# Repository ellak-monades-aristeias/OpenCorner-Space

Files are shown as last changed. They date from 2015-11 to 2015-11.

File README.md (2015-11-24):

# OpenCorner-Space
Σκοπός του έργου είναι η δημιουργία ενός ευέλικτου και εύκολου στο στήσιμο συστήματος πατώματος που μπορεί να εφαρμοστεί σε χώρους χωρίς παρέμβαση στο υφιαστάμενο δάπεδο και να φιλοξενήσει pop-up γραφειακούς χώρους, εκδηλώσεις, συνέδρεια, σεμινάρια κ.α. 
Το σύστημα αποτελείται από μονάδες πλαστικών βιομηχανικών παλετών που καλύπτονται από επιφάνειες ξύλου και παραλαβάνουν τις ηλεκτρικές και καλωδιακές εγκαταστάσεις του χώρου (ρεύμα-LAN-τηλέφωνο), αφενός κρύβοντάς τες και αφετέρου διοχετεύοντάς τις στα σημεία όπου είναι απαραίτητες χωρίς αναγκαιότητα μηχανολογικής μελέτης. Έτσι σε ορισμένες παλέτες εμφανίζονται με κατάλληλη σήμανση φωλιές που ο χρήστης μπορεί να ανασηκώσει και να συνδεθεί με τις παροχές. 
Οι ίδιες παλέτες μπορούν να δημιουργήσουν διάφορα μικροεπίπεδα στο χώρο, είτε διαχωρίζοντας έτσι λειτουργίες (κίνηση-στάση, εργασία-ανάπαυση), είτε ακόμα δημιουργώντας καθιστικούς χώρους ανάπαυλας σε επίπεδα, αμφιθεατρικές διαρρυθμίσεις για παρουσιάσεις κ.α  
Τα υλικά της πρότασης είναι απλά και σχετικά χαμηλού κόστους (χρησιμοποιούνται μεταχειρισμένες παλέτες), μεταφέρονται και τοποθετούνται εξαιρετικά απλά, προσαρμόζονται στο μέγεθος και τα χαρακτηριστικά του εκάστοτε χώρου χωρίς να απαιτούν καμία μόνιμη επέμβαση και φυσικά επαναχρησιμοποιούνται. 

## Σε ποίους απευθύνεται - Κοινότητες Χρηστών - Προγραμματιστών(Developers) ##
Χρήστες μπορεί να είναι οργανισμοί, ιδρύματα, δήμοι, ιδιωτικές πρωτοβουλίες για start-ups, εκπαιδευτικά ιδρύματα, φοιτητές κ.α

## Κόστος ##
 ... το επιπλέον κόστος για την χρήση του έργου σας, εάν απαιτείται επιπλέον εξοπλισμός η/και κατασκευή το κόστος ανα μονάδα για 1, 10 ή 100. ...

# Παραδοτέα:  
Κατασκευή δαπέδου επιφανείας 3,60 χ 4,00μ ή μεγαλυτέρου αν είναι δυνατόν από χρωματιστές πλαστικές παλέτες με τελείωμα ξύλου (σανίδες ή επιφάνεια) και λεπτομέρεια ανοίγματος μερους του δαπέδου για να περαστούν καλώδια, πρίζες κλπ.

Τεύχος κατασκευαστικών σχεδίων και οδηγιών κατασκευής

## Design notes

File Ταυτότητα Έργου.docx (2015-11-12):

Ταυτότητα Έργου
OpenCorner: Space
- opendesign -

Σκοπός του OpenCorner: Space είναι η δημιουργία ενός ευέλικτου και εύκολου στο στήσιμο συστήματος πατώματος και πανέλων απομόνωσης χώρου, που μπορεί να εφαρμοστεί σε χώρους χωρίς παρέμβαση στο υφιαστάμενο δάπεδο και να φιλοξενήσει pop-up γραφειακούς χώρους, εκδηλώσεις, συνέδρεια, σεμινάρια κ.α. ανάλογα με τις ανάγκες και τον εκάστοτε χώρο.

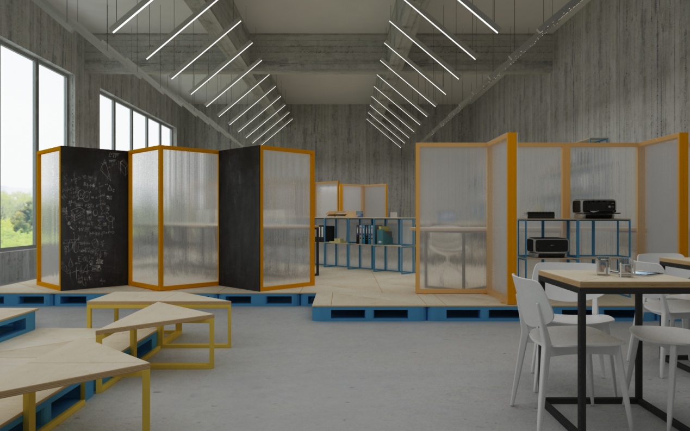
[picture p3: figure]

Υλοποίηση

Xρησιμοποιεί υλικά που είναι διαθέσιμα στην αγορά και απλές λύσεις κατασκευής για να διατηρεί χαμηλό το κόστος κατασκευής.

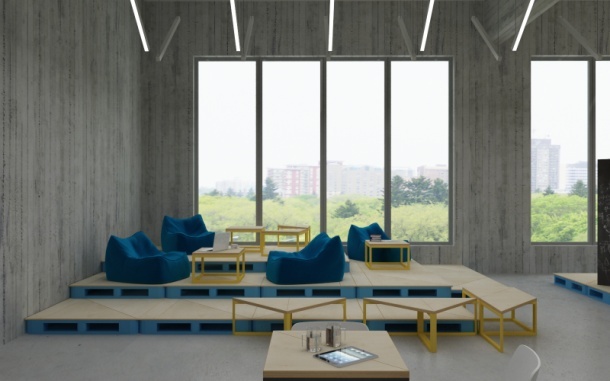
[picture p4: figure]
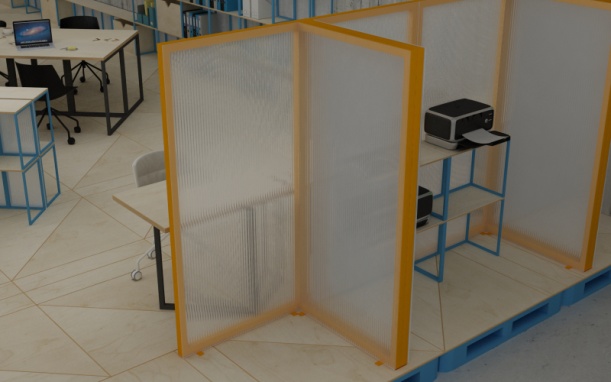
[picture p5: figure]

Η κατασκευή κάθε μονάδας δαπέδου (1.00 χ 1.20) έχει γίνει με:

- 1 βιομηχανική μεταχειρισμένη πλαστική παλέτα 1.00χ1.20χ0.15μ

- 1 φύλλο κόντρα πλακέ 9χιλ. κομμένο 1.00 χ 1.20

- 1 φύλλο κόντρα πλακέ 15 χιλ. κομμένο 1.00 χ 1.20

- Κόψιμο, τρίψιμο, βερνίκωμα των ξύλων

- Τρύπημα της παλέτας όπου περνούν ηλεκτρικές εγκαταστάσεις

- Μοντάρισμα των στοιχείων μεταξύ τους

- Εγκατάσταση πριζών και υποδοχών τηλεφώνου, δικτύου

Κόστος 1 τεμαχίου: 260 ευρώ

Κόστος 10 τεμαχίων: 1400 ευρώ

Κόστος 100 τεμαχίων: 9400 ευρώ

Η κατασκευή για κάθε πέτασμα γωνιακό 0.90 χ 0.90 χ 1.80 (1 μεταλλική γωνία, 2 φύλλα πολυκαρβονικού, 2 πανέλα πλήρωσης (για μαρκαδόρο και με τσόχα), μαγνήτες, έχει γίνει με τις παρακάτω εργασίες:

Μεταλλικές κατασκευές: 6 γωνιών διαφόρων μεγεθών

Προμήθεια και κοπή ξυλείας

Χαράξεις στο κόντρα πλακέ με cnc mill

Προμήθεια και εγκατάσταση μαγνητών

Βαψίματα βερνικώματα όλων των στοιχείων

Πανέλα πολυκαρβονικού

Πανέλα για γραφή με μαρκαδόρο και / ή τελική επιφάνεια τσόχας (για ηχομόνωση)

Τα σχέδια υλοποιήθηκαν με autoCAD, ενώ διατίθενται ελεύθερα

Αποθετήριο

Το αποθετήριο μπορεί να βρεθεί στο github (https://github.com/ellak-monades-aristeias/OpenCorner-Space), υπό την άδεια χρήσης CC BY-SA 4.0 (https://creativecommons.org/licenses/by-sa/4.0/).

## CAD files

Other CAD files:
CAD_/OC_Panel.dwg
CAD_/OC_Flooring.dwg

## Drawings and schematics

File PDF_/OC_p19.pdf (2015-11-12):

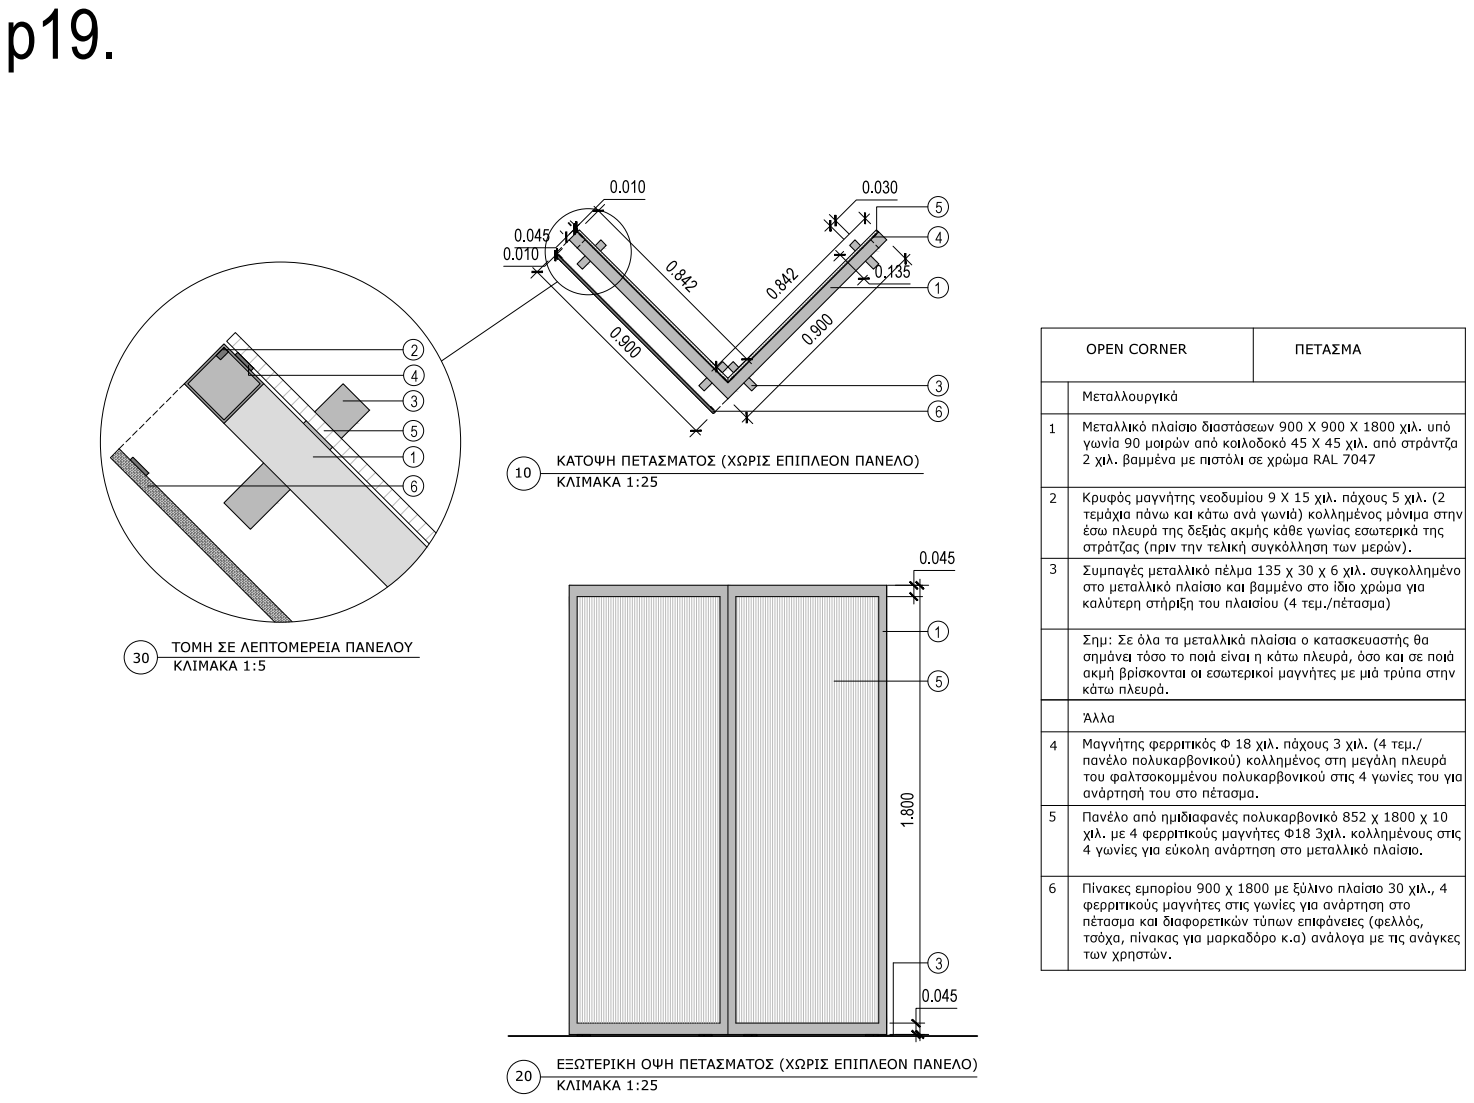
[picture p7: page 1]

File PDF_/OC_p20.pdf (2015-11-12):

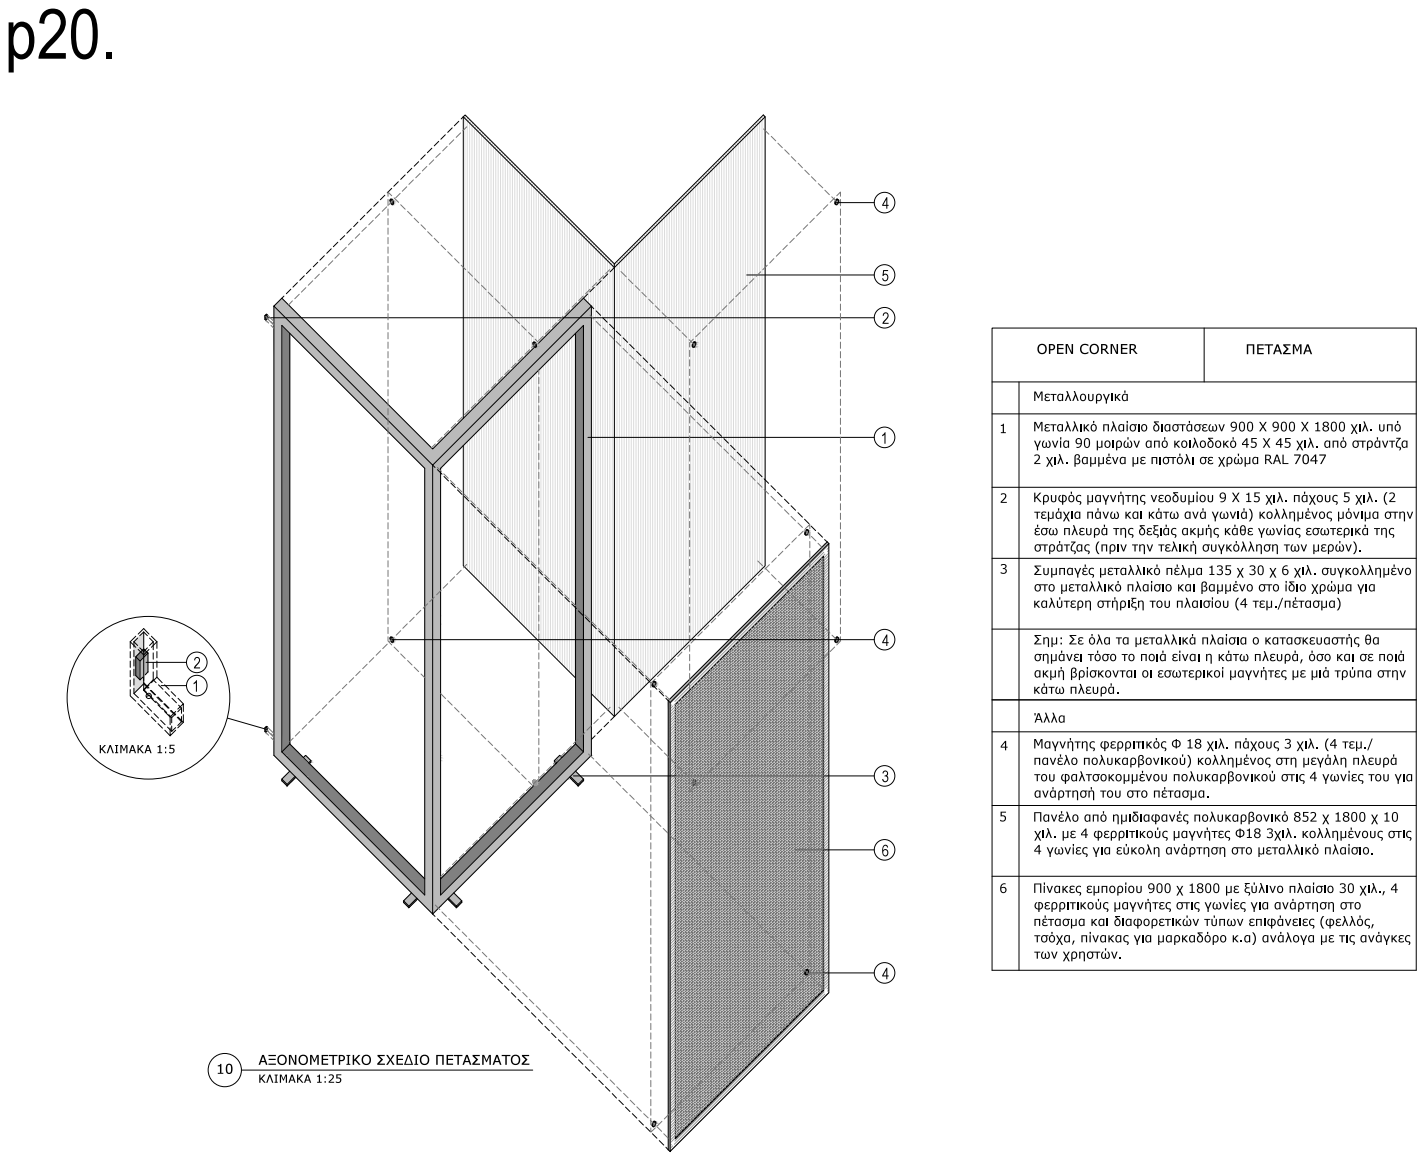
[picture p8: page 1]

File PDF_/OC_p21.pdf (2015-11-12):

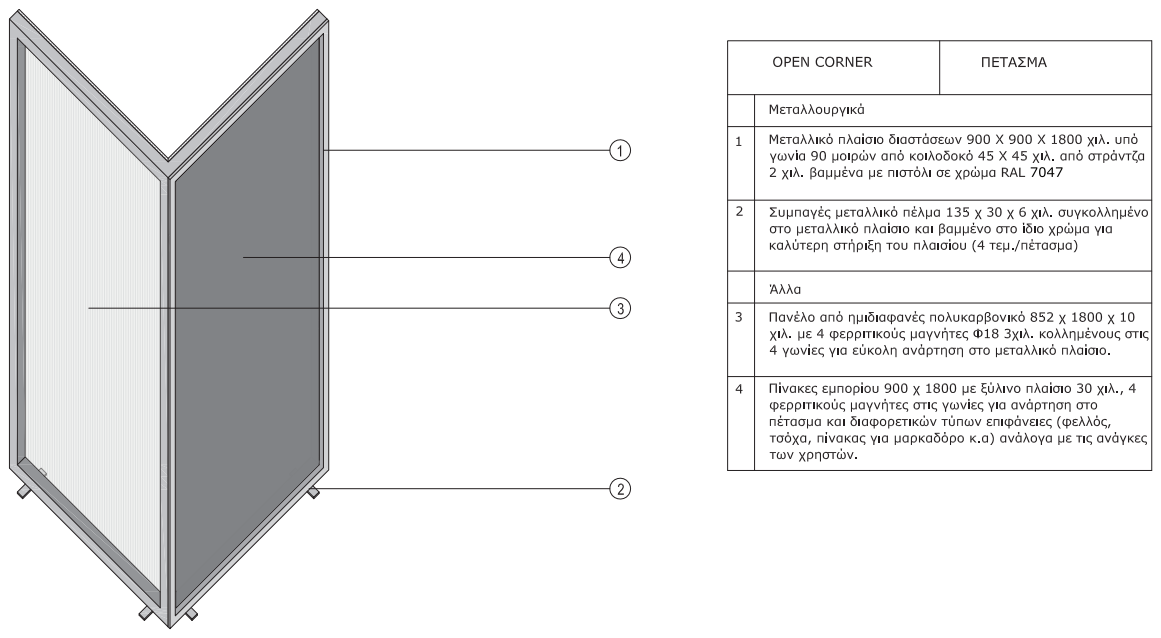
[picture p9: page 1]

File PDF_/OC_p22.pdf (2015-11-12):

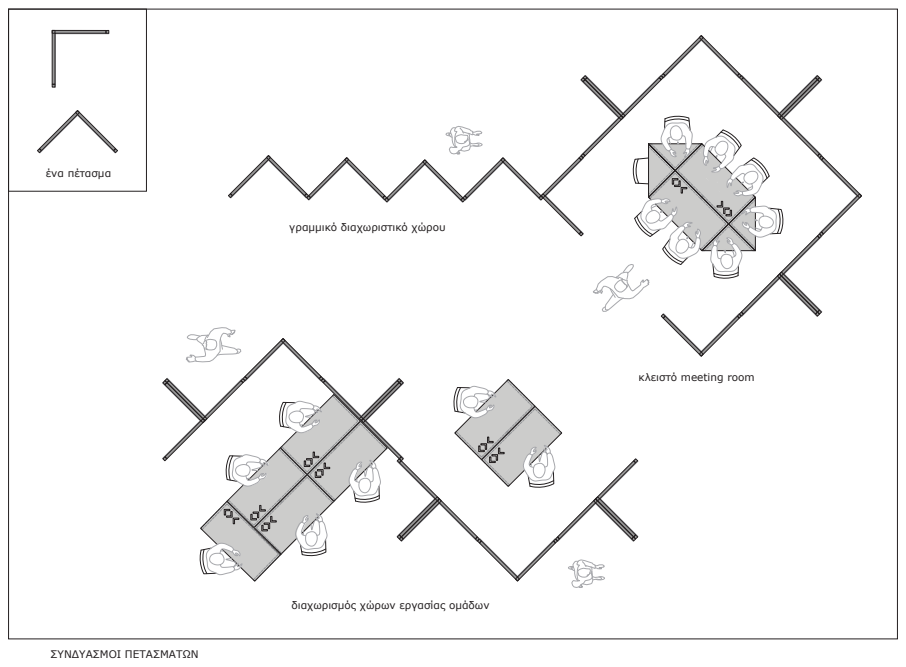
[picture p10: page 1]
ΣΥΝΔΥΑΣΜΟΙ ΠΕΤΑΣΜΑΤΩΝ; ένα πέτασμα

γραμμικό διαχωριστικό χώρου

κλειστό meeting room

διαχωρισμός χώρων εργασίας ομάδων

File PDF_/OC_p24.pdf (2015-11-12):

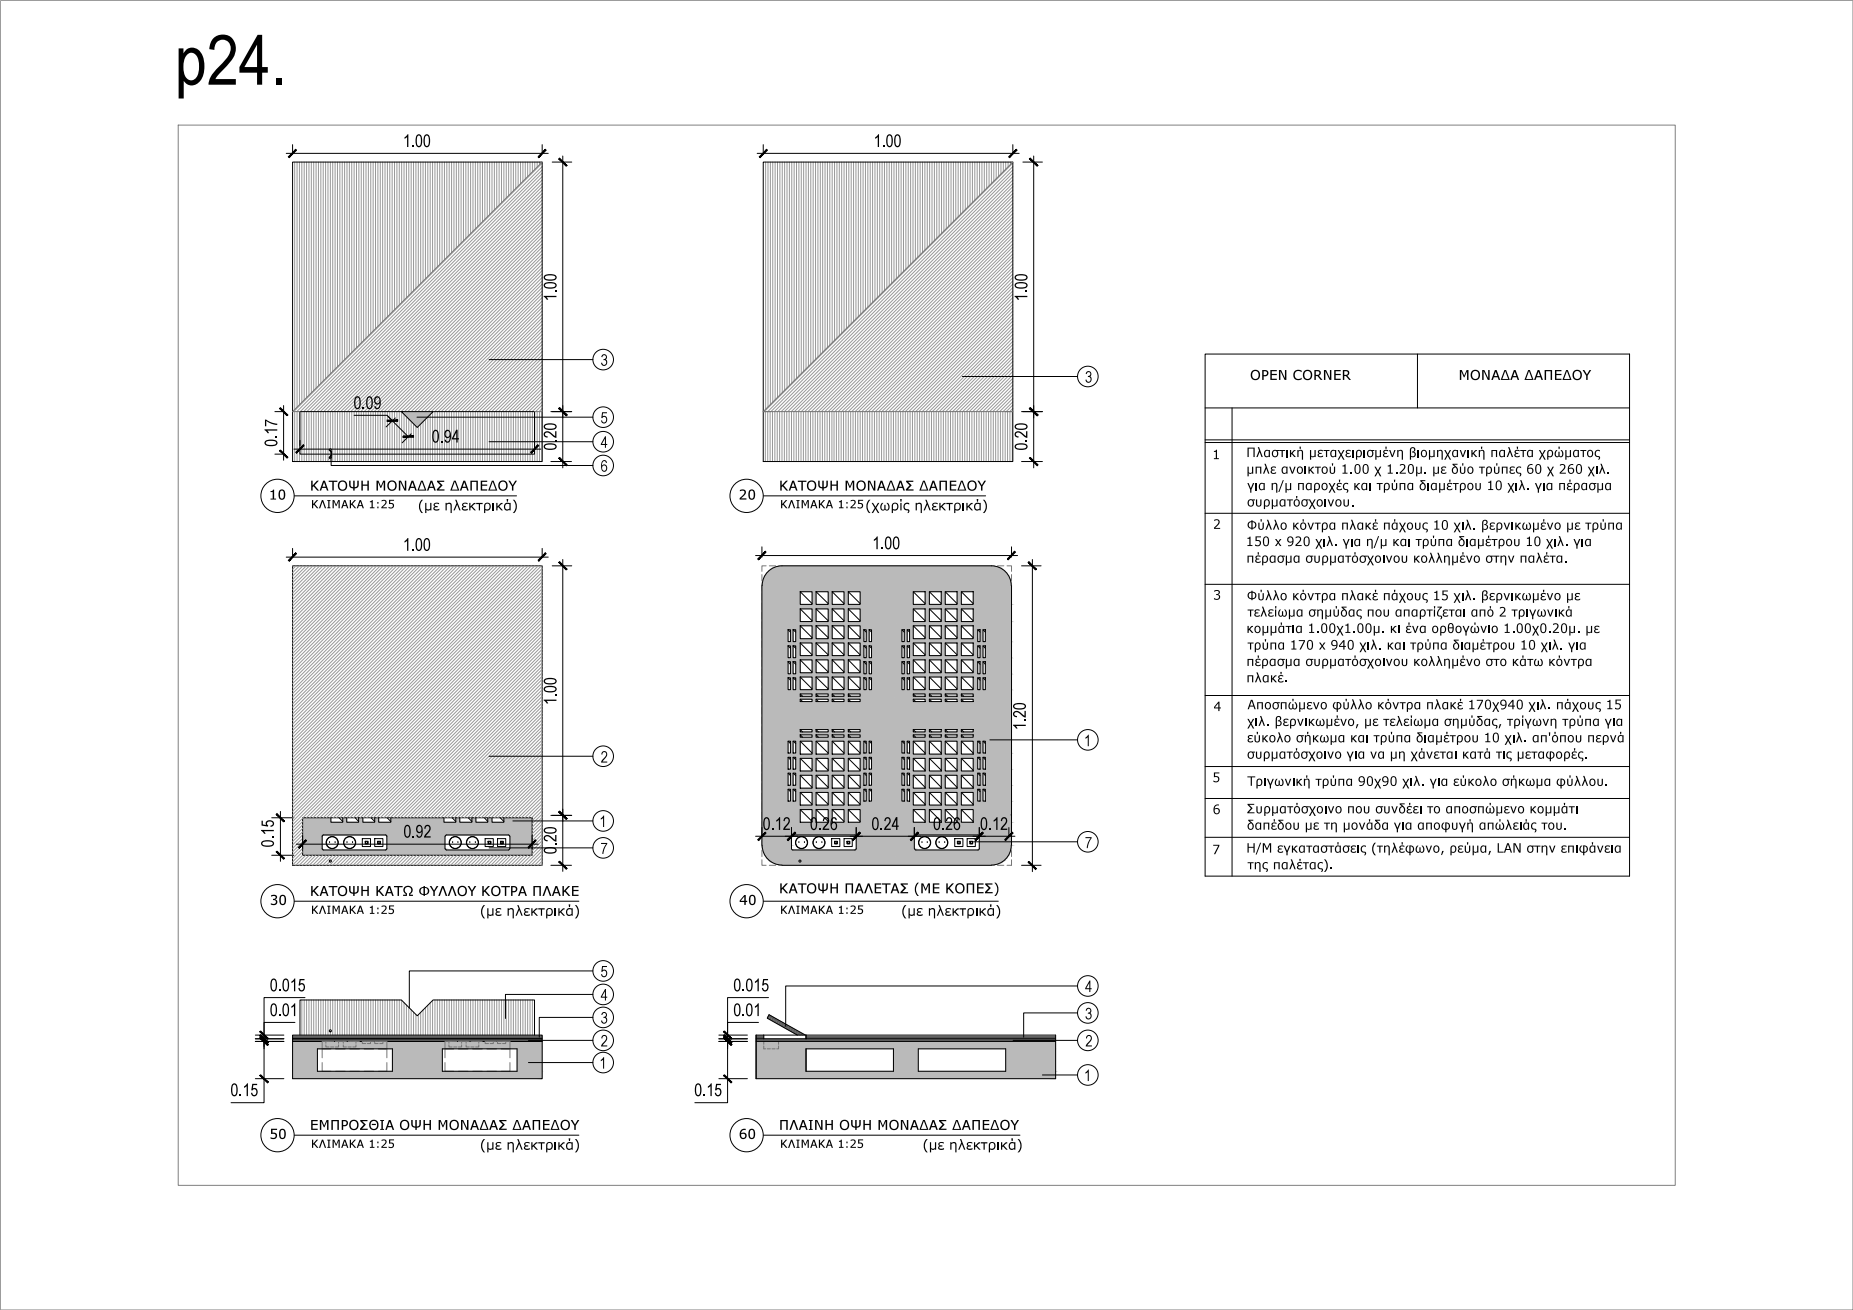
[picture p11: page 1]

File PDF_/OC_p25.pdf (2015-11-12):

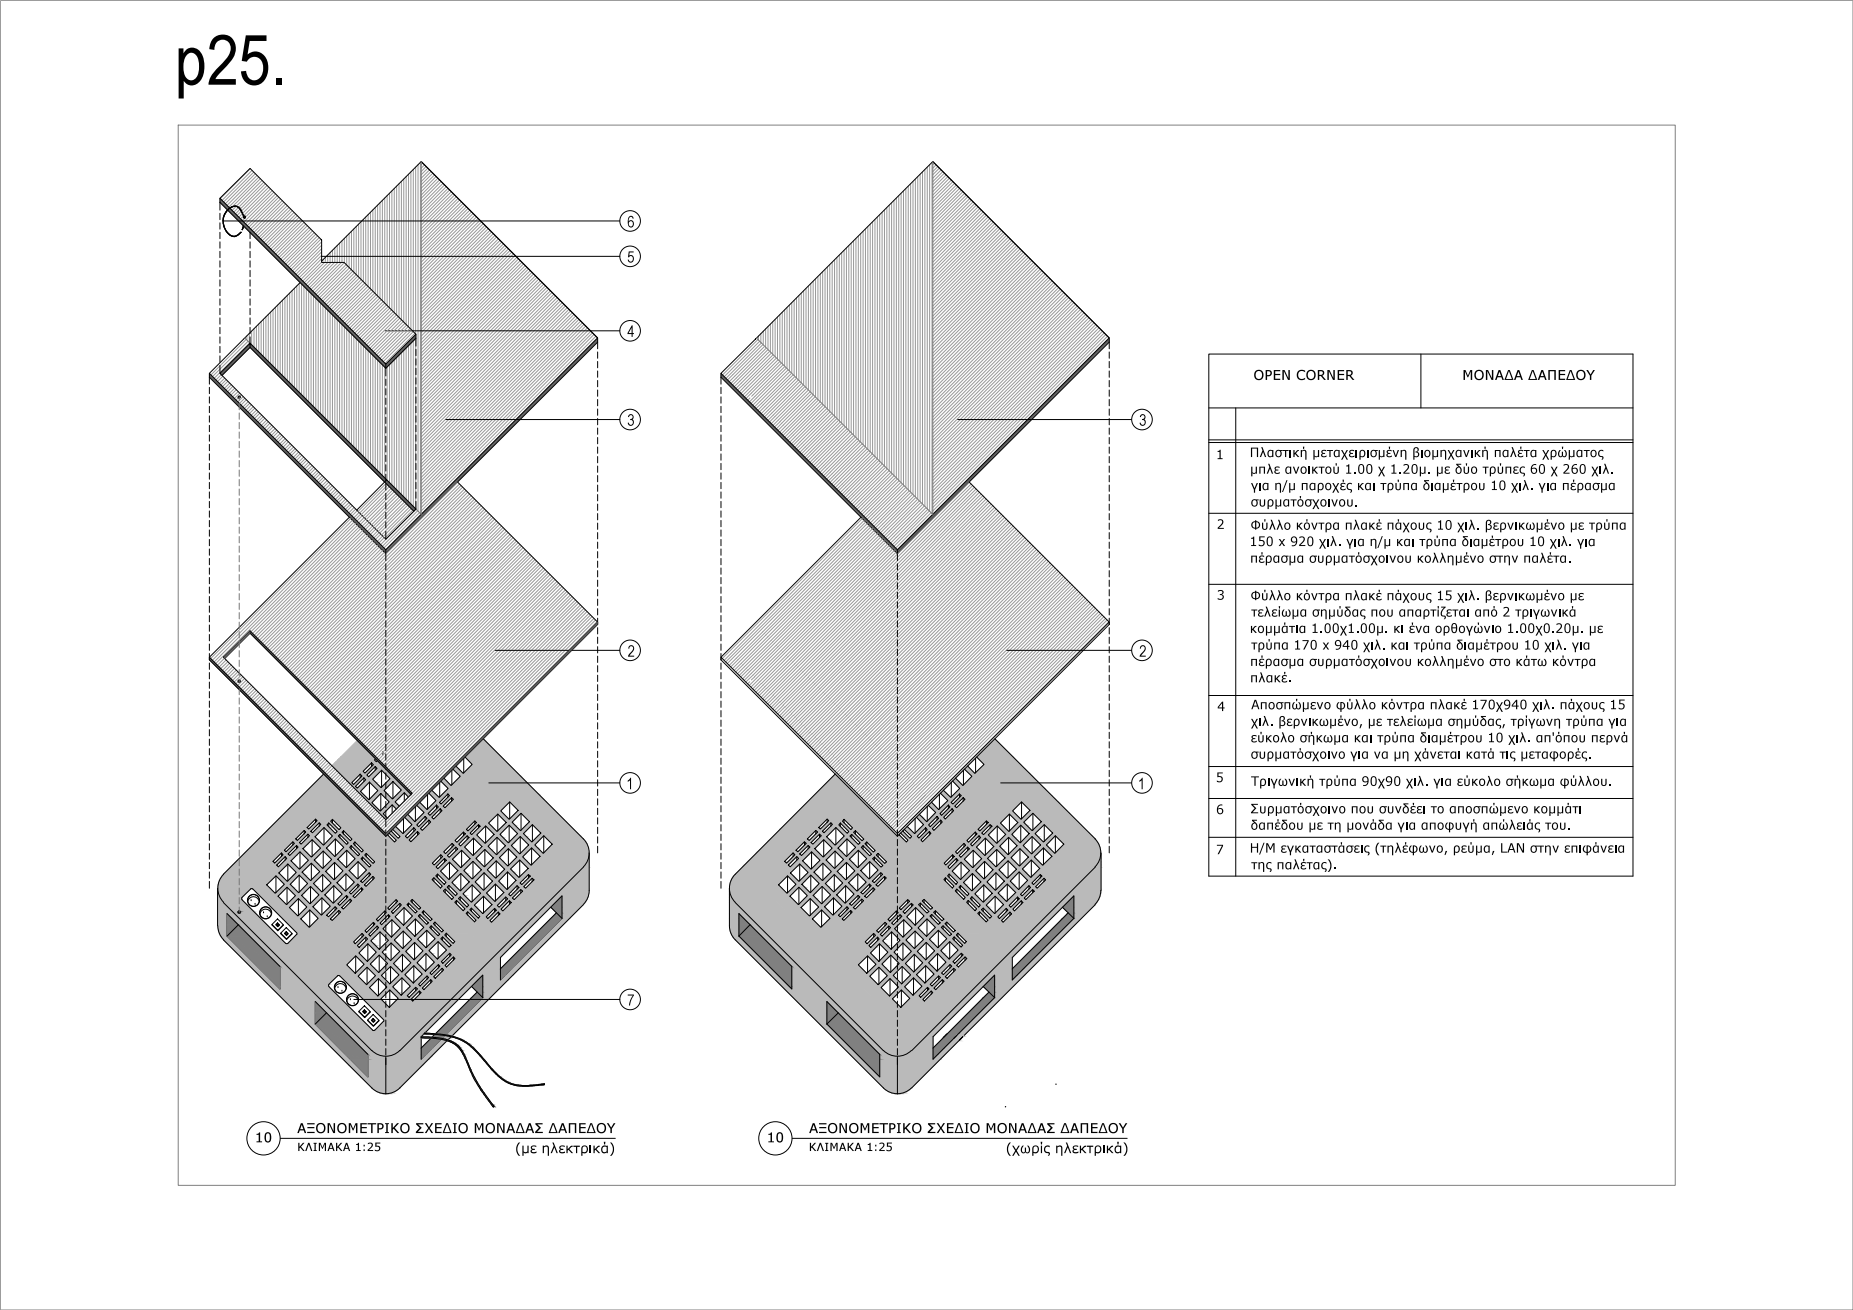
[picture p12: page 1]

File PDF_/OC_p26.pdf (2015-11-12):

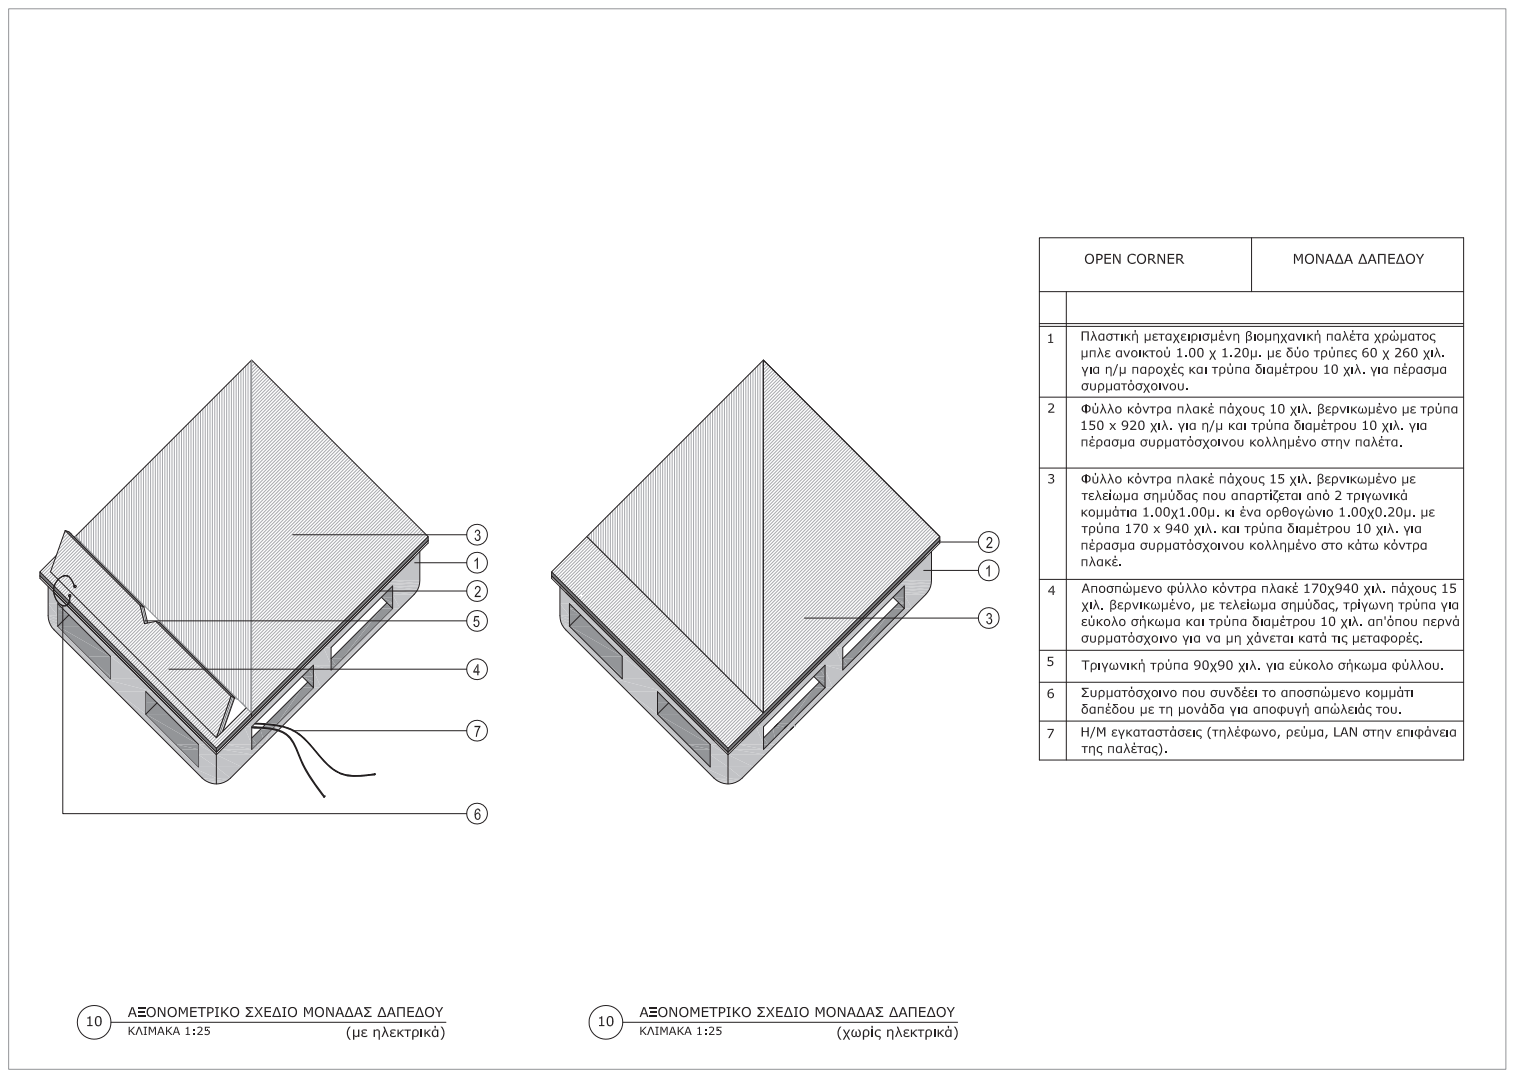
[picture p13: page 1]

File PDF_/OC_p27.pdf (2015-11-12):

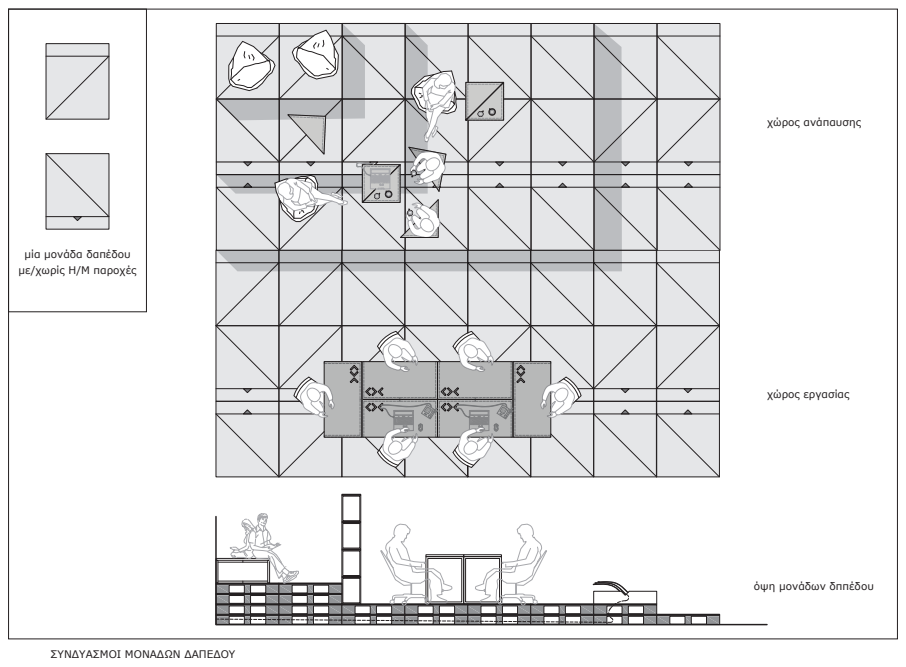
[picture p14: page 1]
χώρος ανάπαυσης; χώρος εργασίας

μία μονάδα δαπέδου
με/χωρίς Η/Μ παροχές

όψη μονάδων δππέδου

ΣΥΝΔΥΑΣΜΟΙ ΜΟΝΑΔΩΝ ΔΑΠΕΔΟΥ

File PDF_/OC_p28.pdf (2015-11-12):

ΡΑΦΙΕΡΑ | ΣΚΑΜΝΙ | ΤΡΑΠΕΖΙ | ΓΡΑΦΕΙΟ | ΠΕΤΑΣΜΑ

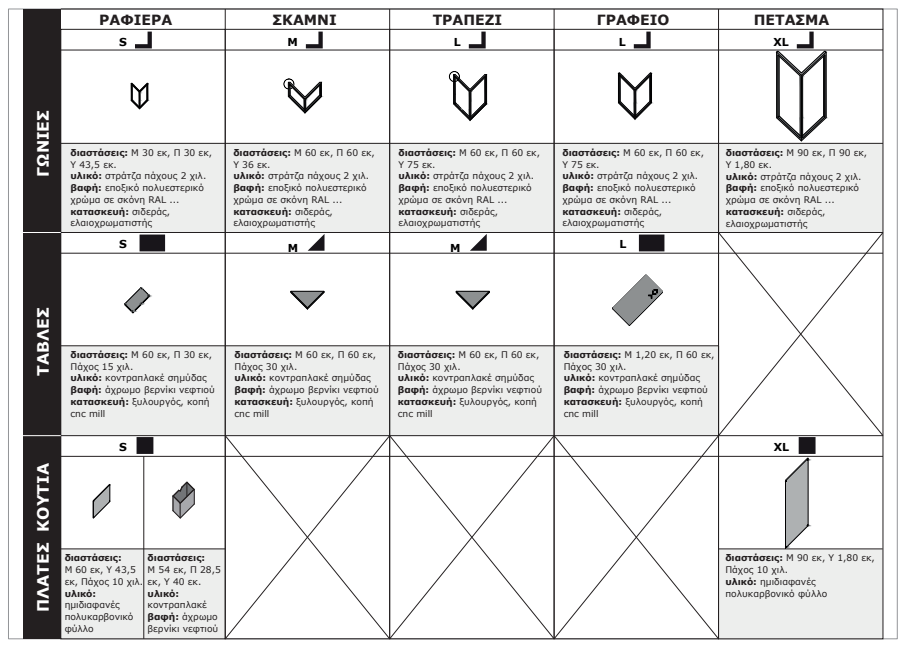
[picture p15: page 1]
ΓΩΝΙΕΣ; διαστάσεις: Μ 54 εκ, Π 28,5 εκ, Υ 40 εκ. υλικό: κοντραπλακέ βαφή: άχρωμο βερνίκι νεφτιού; διαστάσεις: Μ 60 εκ, Y 43,5 εκ, Πάχος 10 χιλ. υλικό: ημιδιαφανές πολυκαρβονικό φύλλο

διαστάσεις: Μ 30 εκ, Π 30 εκ,
υλικό: στράτζα πάχους 2 χιλ.
βαφή: εποξικό πολυεστερικό
χρώμα σε σκόνη RAL ...
κατασκευή: σιδεράς,
ελαιοχρωματιστής

διαστάσεις: Μ 60 εκ, Π 60 εκ,

διαστάσεις: Μ 90 εκ, Π 90 εκ,

ΤΑΒΛΕΣ ΠΛΑΤΕΣ ΚΟΥΤΙΑ

διαστάσεις: Μ 60 εκ, Π 30 εκ,
Πάχος 15 χιλ.
υλικό: κοντραπλακέ σημύδας
βαφή: άχρωμο βερνίκι νεφτιού
κατασκευή: ξυλουργός, κοπή
cnc mill

Πάχος 30 χιλ.

διαστάσεις: Μ 1,20 εκ, Π 60 εκ,

διαστάσεις: Μ 90 εκ, Y 1,80 εκ,
Πάχος 10 χιλ.
υλικό: ημιδιαφανές
πολυκαρβονικό φύλλο
